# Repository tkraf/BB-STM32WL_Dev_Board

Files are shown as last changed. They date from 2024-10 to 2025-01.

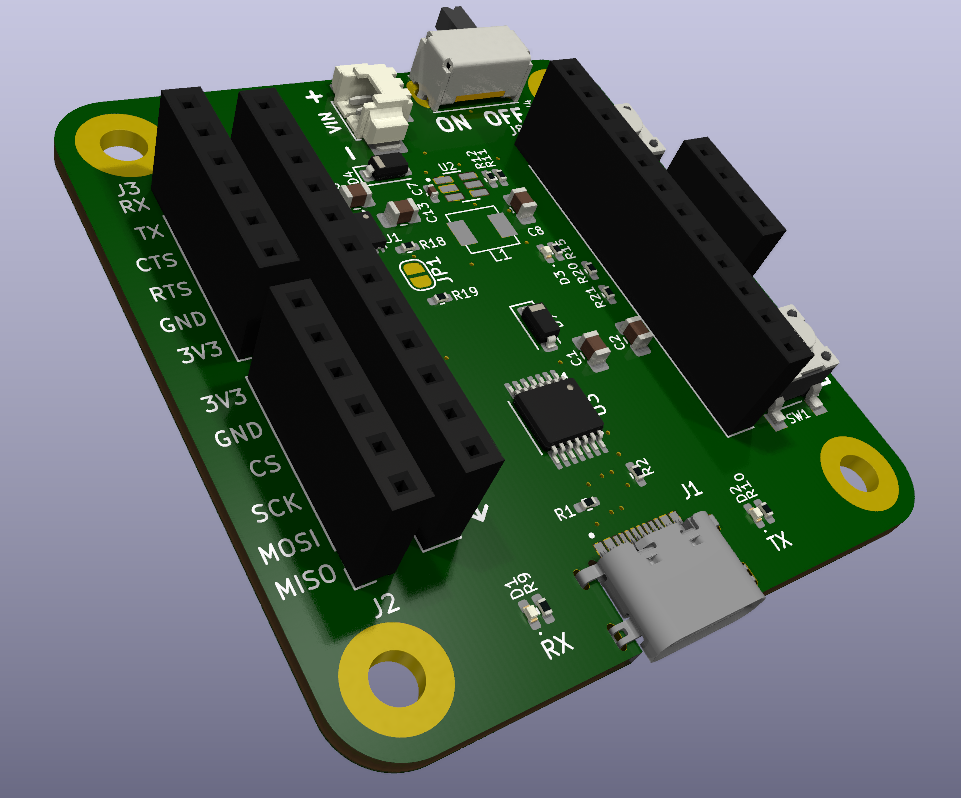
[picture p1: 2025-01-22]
Images/BL Render.png

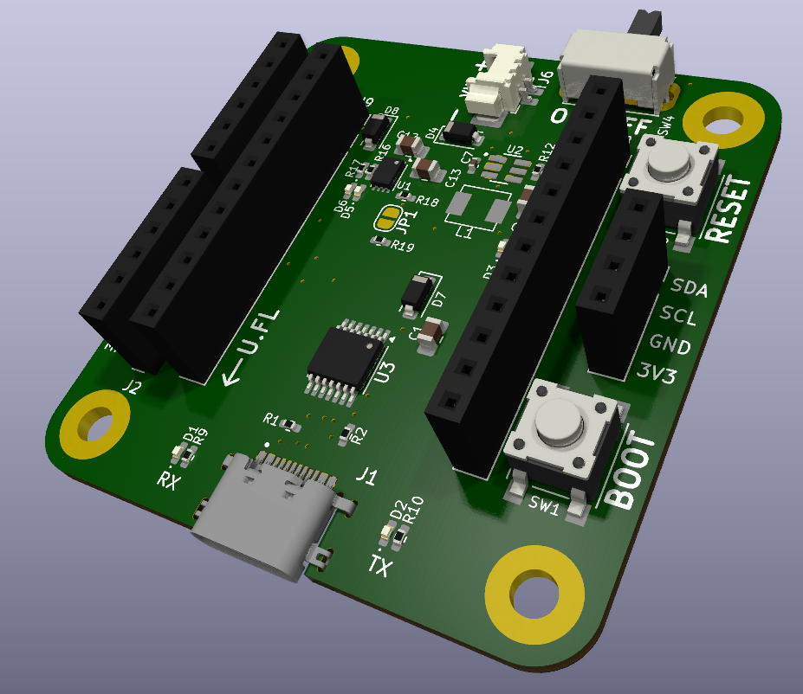
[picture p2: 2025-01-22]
Images/BR Render.png

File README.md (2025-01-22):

# BB-STM32WL_Dev_Board

A development board for the BB-STM32WL that supports LiPo batteries, solar charging, USB programming, and a virtual COM port.

## Features

- **LiPo Battery Support**: Easily connect and use LiPo batteries for power.
- **Solar Charging**: Integrated solar charging capabilities to keep your board powered sustainably.
- **USB Programming**: Convenient USB interface for programming the device.
- **Virtual COM Port**: Access a virtual COM port for serial communication.

### Setup

1. **Powering the Board**:
    - Connect a LiPo battery to the BAT connector on the back of the board.
    - Optionally, connect a solar panel to the VIN connector.
    - The board can also be powered through the USB port.

2. **Programming**:
    - Connect the board to your computer using a USB cable.
    - The board should be recognized as a USB Serial device.
    - Use your preferred development environment to program the board.

3. **Using the Virtual COM Port**:
    - Once connected via USB, the board will provide a virtual COM port.
    - Use any serial communication software to interact with the board.

## License

This project is licensed under the MIT License. See the [LICENSE](https://github.com/tkraf/BB-STM32WL_Dev_Board/blob/main/LICENSE) file for details.

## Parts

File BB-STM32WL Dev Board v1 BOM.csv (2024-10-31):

Reference | Value | Datasheet | Footprint | Qty | DNP | Manufacturer_Name | Manufacturer_Part_Number
C1,C3,C5,C7 | 4.7uF | ~ | Capacitor_SMD:C_0402_1005Metric_Pad0.74x0.62mm_HandSolder | 4 |  | Samsung | CL05A475MP5NRNC
C2,C4,C6 | 0.1uF | ~ | Capacitor_SMD:C_0402_1005Metric_Pad0.74x0.62mm_HandSolder | 3 |  | Samsung | CL05B104KP5NNNC
C8 | 22uF | ~ | Capacitor_SMD:C_0805_2012Metric_Pad1.18x1.45mm_HandSolder | 1 |  | Samsung | CL21A226MAYNNNE
C12,C13 | 10uF | ~ | Capacitor_SMD:C_0402_1005Metric_Pad0.74x0.62mm_HandSolder | 2 |  | Samsung | CL21A106KOQNNNE
D1 | TX | ~ | LED_SMD:LED_0402_1005Metric_Pad0.77x0.64mm_HandSolder | 1 |  | Harvatek | B1811URO-20D000113U1930
D2 | RX | ~ | LED_SMD:LED_0402_1005Metric_Pad0.77x0.64mm_HandSolder | 1 |  | Harvatek | B1811URO-20D000113U1930
D3 | LED_Small | ~ | LED_SMD:LED_0402_1005Metric_Pad0.77x0.64mm_HandSolder | 1 |  | Harvatek | B1811URO-20D000113U1930
D4,D7,D8 | ~ |  | Diode_SMD:D_SOD-123 | 3 |  | Panjit International Inc. | SBA140AS_R1_00001
D5 | POWER | ~ | LED_SMD:LED_0402_1005Metric_Pad0.77x0.64mm_HandSolder | 1 |  | Harvatek | B1811URO-20D000113U1930
D6 | FULL | ~ | LED_SMD:LED_0402_1005Metric_Pad0.77x0.64mm_HandSolder | 1 |  | Harvatek | B1811URO-20D000113U1930
IC1 | FT260Q | https://4donline.ihs.com/images/VipMasterIC/IC/FTDI/FTDI-S-A0014899502/FTDI-S-A0014899502-1.pdf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 | Component Libraries:QFN50P500X500X80-29N-D | 1 |  | FTDI Chip | FT260Q
J1 | 216990-0003 | https://www.molex.com/pdm_docs/sd/2169900003_sd.pdf | Component Libraries:2169900003 | 1 |  | Molex | 216990-0003
J2 | SPI | ~ | Connector_PinSocket_2.54mm:PinSocket_1x06_P2.54mm_Vertical | 1 |  | Wurth | 61300611821
J3 | USART | ~ | Connector_PinSocket_2.54mm:PinSocket_1x06_P2.54mm_Vertical | 1 |  | Wurth | 61300611821
J4 | SWD | ~ |  | 1 | DNP
J5 | I2C | ~ | Connector_PinSocket_2.54mm:PinSocket_1x04_P2.54mm_Vertical | 1 |  | Wurth | 61300411821
J6 | 3V-16V | ~ | Connector_Molex:Molex_PicoBlade_53261-0271_1x02-1MP_P1.25mm_Horizontal | 1 |  | Molex | 0532610271
J7 | BATTERY | ~ | Connector_Molex:Molex_PicoBlade_53261-0271_1x02-1MP_P1.25mm_Horizontal | 1 |  | Molex | 0532610271
L1 | 1uH | ~ | Inductor_SMD:L_Coilcraft_XxL4020 | 1 |  | CoilCraft | XFL4020-102MEB
M1 | ~ |  | Wireless_Custom:BB-STM32WL | 1 |  | Wurth | 61301211821
R1,R2 | 5.1k | ~ | Resistor_SMD:R_0402_1005Metric_Pad0.72x0.64mm_HandSolder | 2 |  | Yageo | RC0402FR-075K1L
R3 | 5k1 | ~ | Resistor_SMD:R_0402_1005Metric_Pad0.72x0.64mm_HandSolder | 1 |  | Yageo | RC0402FR-075K1L
R4,R5 | 33 | ~ | Resistor_SMD:R_0402_1005Metric_Pad0.72x0.64mm_HandSolder | 2 |  | Yageo | RC0402FR-0733RL
R6,R7,R8 | 10K | ~ | Resistor_SMD:R_0402_1005Metric_Pad0.72x0.64mm_HandSolder | 3 |  | Yageo | RC0402JR-0710KL
R9,R10,R15,R16,R17 | 665 | ~ | Resistor_SMD:R_0402_1005Metric_Pad0.72x0.64mm_HandSolder | 5 |  | Panasonic | ERJ-2RKF6650X
R11 | 453K | ~ | Resistor_SMD:R_0402_1005Metric_Pad0.72x0.64mm_HandSolder | 1 |  | Vishay | CRCW0402453KFKED
R12 | 100K | ~ | Resistor_SMD:R_0402_1005Metric_Pad0.72x0.64mm_HandSolder | 1 |  | Vishay | CRCW0402100KFKED
R18,R19 | 1K | ~ | Resistor_SMD:R_0402_1005Metric_Pad0.72x0.64mm_HandSolder | 2 |  | Yageo | RC0402JR-071KL
R20 | 50K | ~ | Resistor_SMD:R_0402_1005Metric_Pad0.72x0.64mm_HandSolder | 1 |  | Stackpole | RNCF0402DKE50K0
R21 | 97K | ~ | Resistor_SMD:R_0402_1005Metric_Pad0.72x0.64mm_HandSolder | 1 |  | Yageo | RC0402FR-0797K6L
SW1 | BOOT | ~ | Button_Switch_SMD:SW_Push_1P1T_NO_6x6mm_H9.5mm | 1
SW2 | RESET | ~ | Button_Switch_SMD:SW_Push_1P1T_NO_6x6mm_H9.5mm | 1
SW4 | ON_OFF | ~ | Button_Switch_THT:SW_Slide_SPDT_Angled_CK_OS102011MA1Q | 1 |  | Same Sky | SLW-864574-5A-RA-N-D
TP1 | TestPoint | ~ | TestPoint:TestPoint_Loop_D1.80mm_Drill1.0mm_Beaded | 1 | DNP
U1 | MCP73831-2-MC | http://ww1.microchip.com/downloads/en/DeviceDoc/20001984g.pdf | Package_DFN_QFN:DFN-8-1EP_3x2mm_P0.5mm_EP1.7x1.4mm | 1 |  | Microchip | MCP73831T-2ACI/MC
U2 | TLV62569PDDCR |  | Component Libraries:SOT95P280X110-6N | 1 |  | TI | TLV62569PDDCR

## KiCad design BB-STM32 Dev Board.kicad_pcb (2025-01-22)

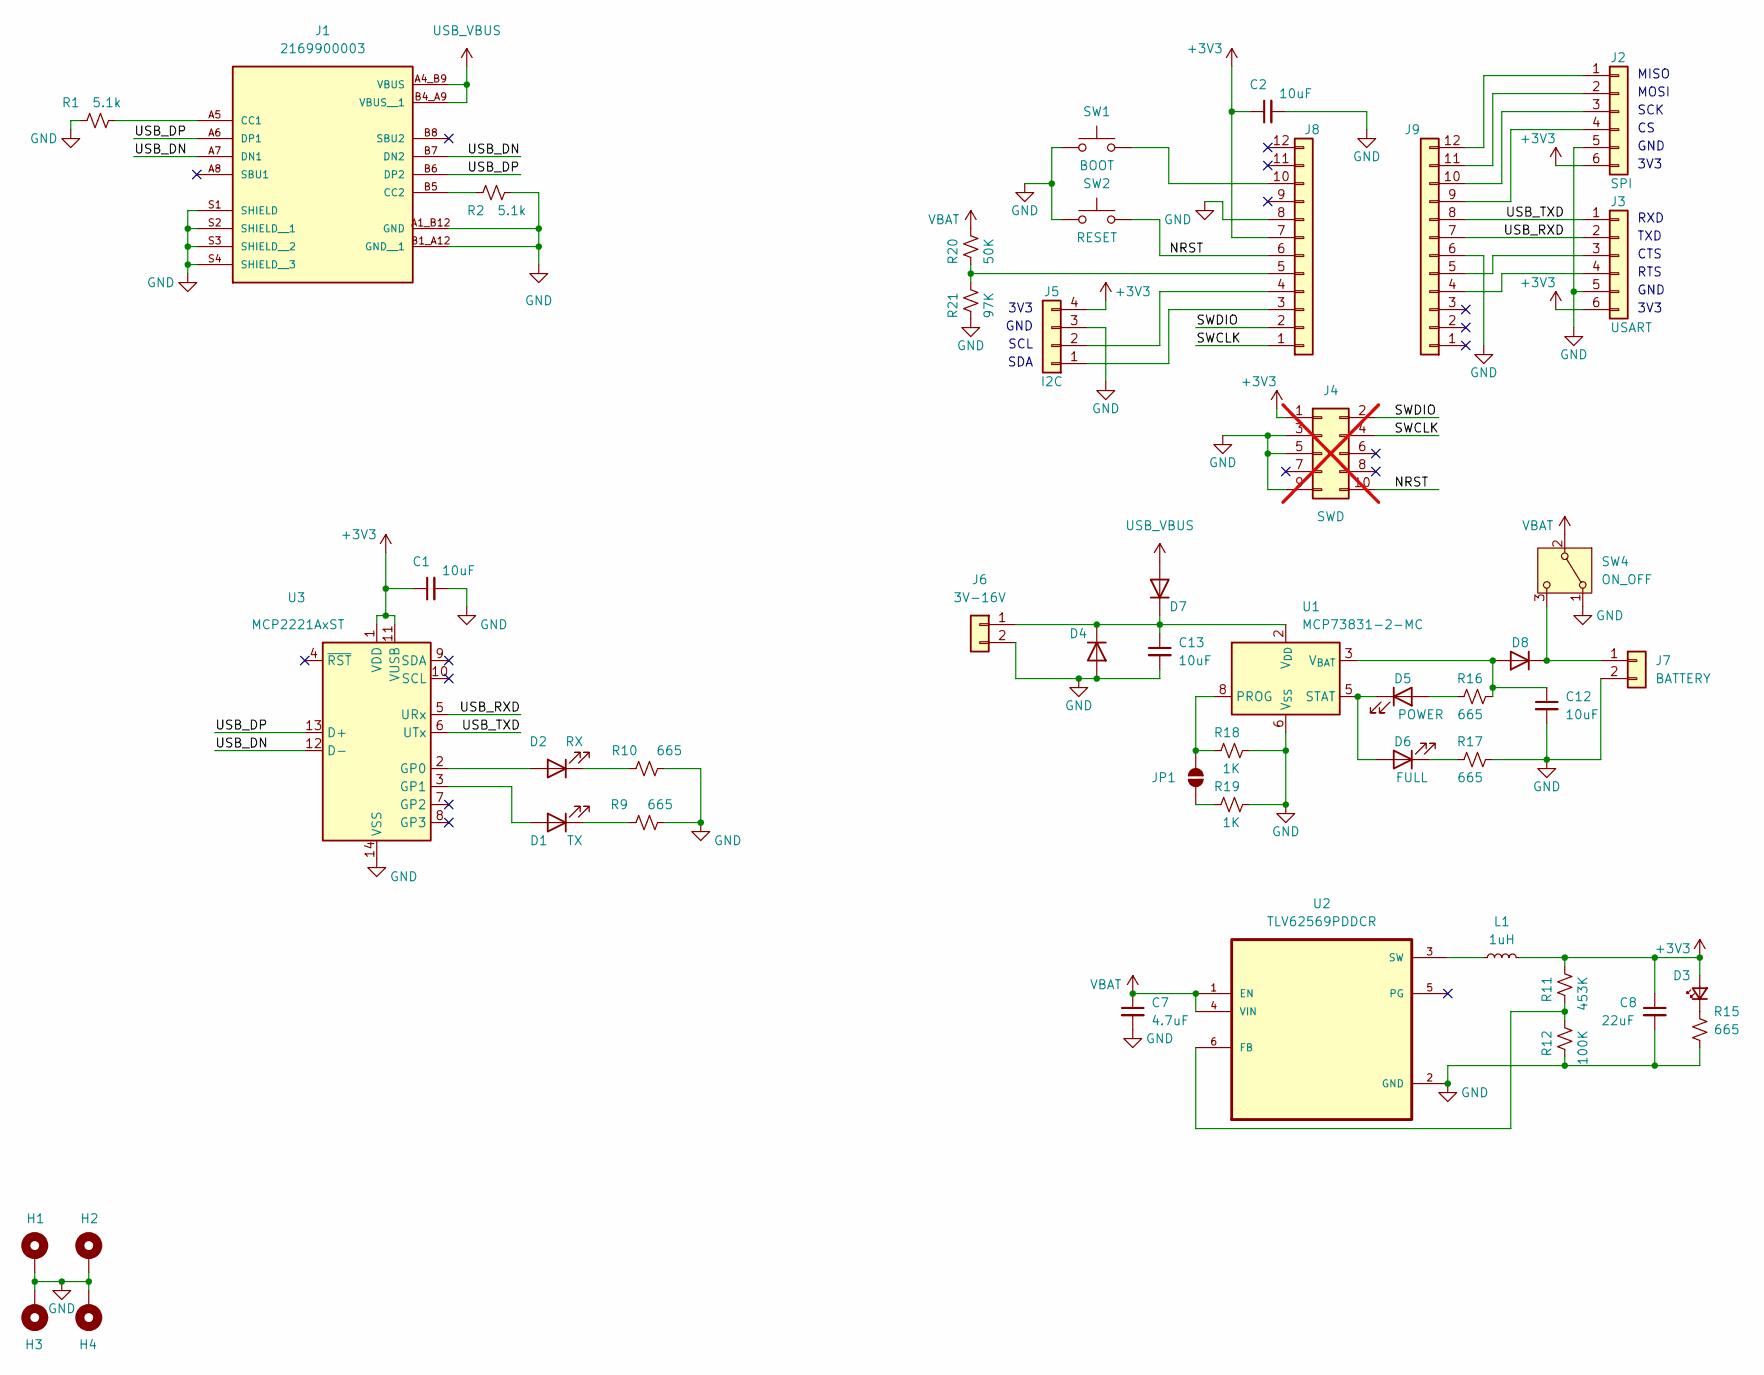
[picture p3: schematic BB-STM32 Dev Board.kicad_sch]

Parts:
C1, C2, C12, C13: 10uF; C_0805_2012Metric_Pad1.18x1.45mm_HandSolder; Manufacturer_Part_Number CL21A106KOQNNNE
C7: 4.7uF; C_0402_1005Metric_Pad0.74x0.62mm_HandSolder; Manufacturer_Part_Number CL05A475MP5NRNC
C8: 22uF; C_0805_2012Metric_Pad1.18x1.45mm_HandSolder; Manufacturer_Part_Number CL21A226MAYNNNE
D1: TX; LED_0402_1005Metric_Pad0.77x0.64mm_HandSolder; Manufacturer_Part_Number B1811URO-20D000113U1930
D2: RX; LED_0402_1005Metric_Pad0.77x0.64mm_HandSolder; Manufacturer_Part_Number B1811URO-20D000113U1930
D3: LED_Small; LED_0402_1005Metric_Pad0.77x0.64mm_HandSolder; Manufacturer_Part_Number B1811URO-20D000113U1930
D4, D7, D8: D_SOD-123; Manufacturer_Part_Number SBA140AS_R1_00001
D5: POWER; LED_0402_1005Metric_Pad0.77x0.64mm_HandSolder; Manufacturer_Part_Number B1811URO-20D000113U1930
D6: FULL; LED_0402_1005Metric_Pad0.77x0.64mm_HandSolder; Manufacturer_Part_Number B1811URO-20D000113U1930
H1, H2, H3, H4: MountingHole_Pad; MountingHole_3.2mm_M3_Pad_TopBottom
J1: 2169900003; MOLEX_2169900003; PARTREV A1
J2: SPI; PinSocket_1x06_P2.54mm_Vertical; Manufacturer_Part_Number 61300611821
J3: USART; PinSocket_1x06_P2.54mm_Vertical; Manufacturer_Part_Number 61300611821
J4: SWD; not fitted
J5: I2C; PinSocket_1x04_P2.54mm_Vertical; Manufacturer_Part_Number 61300411821
J6: 3V-16V; Molex_PicoBlade_53261-0271_1x02-1MP_P1.25mm_Horizontal; Manufacturer_Part_Number 0532610271
J7: BATTERY; Molex_PicoBlade_53261-0271_1x02-1MP_P1.25mm_Horizontal; Manufacturer_Part_Number 0532610271
J8, J9: Conn_01x12; PinSocket_1x12_P2.54mm_Vertical
JP1: SolderJumper_2_Open; SolderJumper-2_P1.3mm_Open_RoundedPad1.0x1.5mm
L1: 1uH; Bourns SRP4020TA; Manufacturer_Part_Number XFL4020-102MEB
R1, R2: 5.1k; R_0402_1005Metric_Pad0.72x0.64mm_HandSolder; Manufacturer_Part_Number RC0402FR-075K1L
R9, R10, R15, R16, R17: 665; R_0402_1005Metric_Pad0.72x0.64mm_HandSolder; Manufacturer_Part_Number ERJ-2RKF6650X
R11: 453K; R_0402_1005Metric_Pad0.72x0.64mm_HandSolder; Manufacturer_Part_Number CRCW0402453KFKED
R12: 100K; R_0402_1005Metric_Pad0.72x0.64mm_HandSolder; Manufacturer_Part_Number CRCW0402100KFKED
R18, R19: 1K; R_0402_1005Metric_Pad0.72x0.64mm_HandSolder; Manufacturer_Part_Number RC0402JR-071KL
R20: 50K; R_0402_1005Metric_Pad0.72x0.64mm_HandSolder; Manufacturer_Part_Number RNCF0402DKE50K0
R21: 97K; R_0402_1005Metric_Pad0.72x0.64mm_HandSolder; Manufacturer_Part_Number RC0402FR-0797K6L
SW1: BOOT; SW_Push_1P1T_NO_6x6mm_H9.5mm
SW2: RESET; SW_Push_1P1T_NO_6x6mm_H9.5mm
SW4: ON_OFF; SW_Slide_SPDT_Angled_CK_OS102011MA1Q; Manufacturer_Part_Number SLW-864574-5A-RA-N-D
U1: MCP73831-2-MC; DFN-8-1EP_3x2mm_P0.5mm_EP1.7x1.4mm; Manufacturer_Part_Number MCP73831T-2ACI/MC
U2: TLV62569PDDCR; SOT95P280X110-6N; Manufacturer_Part_Number TLV62569PDDCR
U3: MCP2221AxST; TSSOP-14_4.4x5mm_P0.65mm

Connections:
+3V3: C1.1, C2.1, C8.1, D3.2 (A), J2.6, J3.6, J4.1, J5.4, J8.7, L1.2, R11.2, U3.1 (VDD), U3.11 (VUSB)
/NRST: J4.10, J8.6, SW2.2
/SWCLK: J4.4, J8.1
/SWDIO: J4.2, J8.2
/USB_DN: J1.A7 (DN1), J1.B7 (DN2), U3.12 (D-)
/USB_DP: J1.A6 (DP1), J1.B6 (DP2), U3.13 (D+)
/USB_RXD: J3.2, J9.7, U3.5 (URx)
/USB_TXD: J3.1, J9.8, U3.6 (UTx)
GND: C1.2, C2.2, C7.2, C8.2, C12.2, C13.2, D4.2 (A), H1.1, H2.1, H3.1, H4.1, J1.A1_B12 (GND), J1.B1_A12 (GND__1), J1.S1 (SHIELD), J1.S2 (SHIELD__1), J1.S3 (SHIELD__2), J1.S4 (SHIELD__3), J2.5, J3.5, J4.3, J4.5, J4.9, J5.3, J6.2, J7.2, J8.8, J9.6, R1.1, R2.2, R9.2, R10.1, R12.1, R15.2, R17.2, R18.2, R19.2, R21.1, SW1.1, SW2.1, SW4.1 (A), U1.6 (V_{SS}), U2.2 (GND), U3.14 (VSS)
unnamed: D1.2 (A), U3.3 (GP1)
unnamed: D1.1 (K), R9.1
unnamed: D2.2 (A), U3.2 (GP0)
unnamed: D2.1 (K), R10.2
unnamed: D3.1 (K), R15.1
unnamed: C13.1, D4.1 (K), D7.1 (K), J6.1, U1.1 (V_{DD}), U1.2 (V_{DD})
unnamed: D5.2 (A), R16.1
unnamed: D5.1 (K), D6.2 (A), U1.5 (STAT)
unnamed: D6.1 (K), R17.1
unnamed: C12.1, D8.2 (A), R16.2, U1.3 (V_{BAT}), U1.4 (V_{BAT})
unnamed: D8.1 (K), J7.1, SW4.3 (C)
unnamed: J1.A5 (CC1), R1.2
unnamed: J1.B5 (CC2), R2.1
unnamed: J2.1, J9.12
unnamed: J2.2, J9.11
unnamed: J2.3, J9.10
unnamed: J2.4, J9.9
unnamed: J3.3, J9.5
unnamed: J3.4, J9.4
unnamed: J5.1, J8.3
unnamed: J5.2, J8.4
unnamed: J8.5, R20.1, R21.2
unnamed: J8.10, SW1.2
unnamed: JP1.1 (A), R18.1, U1.8 (PROG)
unnamed: JP1.2 (B), R19.1
unnamed: R11.1, R12.2, U2.6 (FB)
unnamed: L1.1, U2.3 (SW)
USB_VBUS: D7.2 (A), J1.A4_B9 (VBUS), J1.B4_A9 (VBUS__1)
VBAT: C7.1, R20.2, SW4.2 (B), U2.1 (EN), U2.4 (VIN)

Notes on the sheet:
MISO
GND
RTS
3V3
TXD
SCL
RXD
MOSI
SDA
CTS
SCK

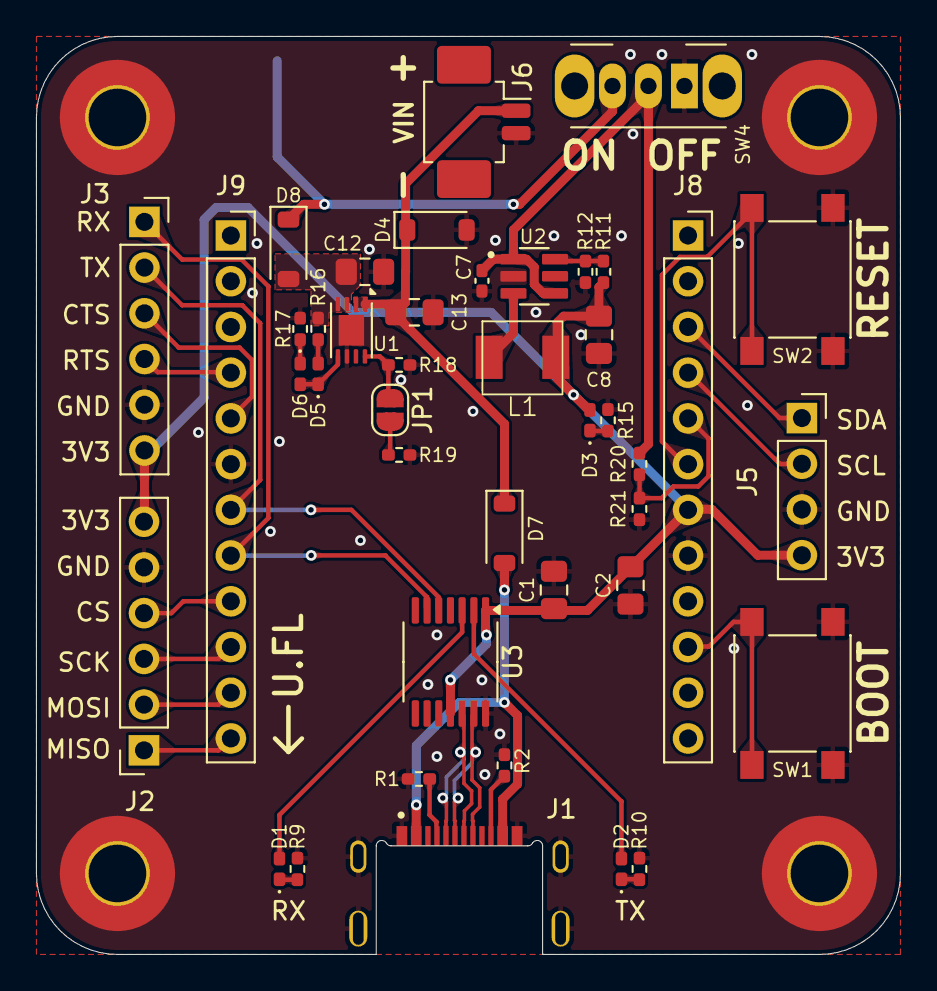
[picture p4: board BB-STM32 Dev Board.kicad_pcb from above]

Board: 2 copper layers, 48.0 x 51.0 mm, 47 parts (1 on the bottom side), 36 nets.

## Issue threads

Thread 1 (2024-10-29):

USB-C Footprint

tkraf, 2024-10-29:
The USB-C connector has the wrong footprint for the connector in the BOM.

tkraf, 2025-01-22:
Fixed in V2

Closed 2025-01-22.

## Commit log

2024-10-11 Nearly Ready Rev0
    [BB-STM32 Dev Board.kicad_pcb, BB-STM32 Dev Board.kicad_sch]
2024-10-30 Create PDF.yml
    Creates the Schematic PDF files.
2024-10-30 Update main.yml
    Adjusted Schematic PDF Actions
2024-10-30 Update main.yml
    Still trying Automatic Schematic creation
2024-10-30 Update main.yml
    More adjustments to the Schematic PDF Workflow.
2024-10-30 Update main.yml
    Changed to Kicad Actions
2024-10-31 Update main.yml
    Back to Kicad PDF
2024-10-31 First Run of board.
    [BB-STM32 Dev Board-EdgeCuts.dxf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]
2024-10-31 Cleaned up Files
    [BB-STM32 Dev Board-EdgeCuts.dxf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]
2025-01-22 Added Images and fixed USB Virtual COM Port.
    [BB-STM32 Dev Board.kicad_pcb, BB-STM32 Dev Board.kicad_sch]
